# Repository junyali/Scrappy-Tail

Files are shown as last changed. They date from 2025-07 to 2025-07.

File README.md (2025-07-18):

# Scrappy Tail

A DIY USB 2.0 Hub with 4 Type-A ports and a Type-C input, with a cute 3D printed scrappy cat case!! :3

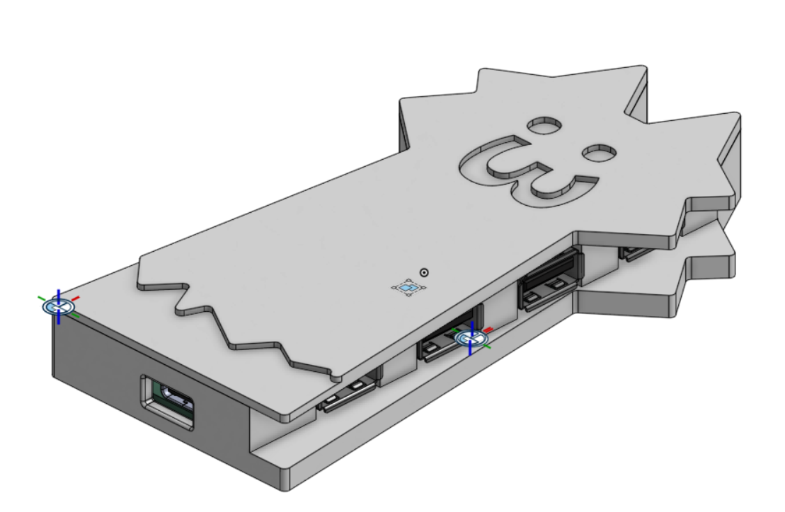
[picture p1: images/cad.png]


Scrappy Tail connects to your device using USB Type-C (hence the cable making it look like a tail!) and gives you 4 additional USB Type-A ports. It uses the SL2.1A hub controller, so it uses USB 2.0 interface and thus speeds are limited to 480Mbps

PCB designed in KiCAD and CAD designed in OnShape. 

# Preview

| Description | Image |
|---|---|
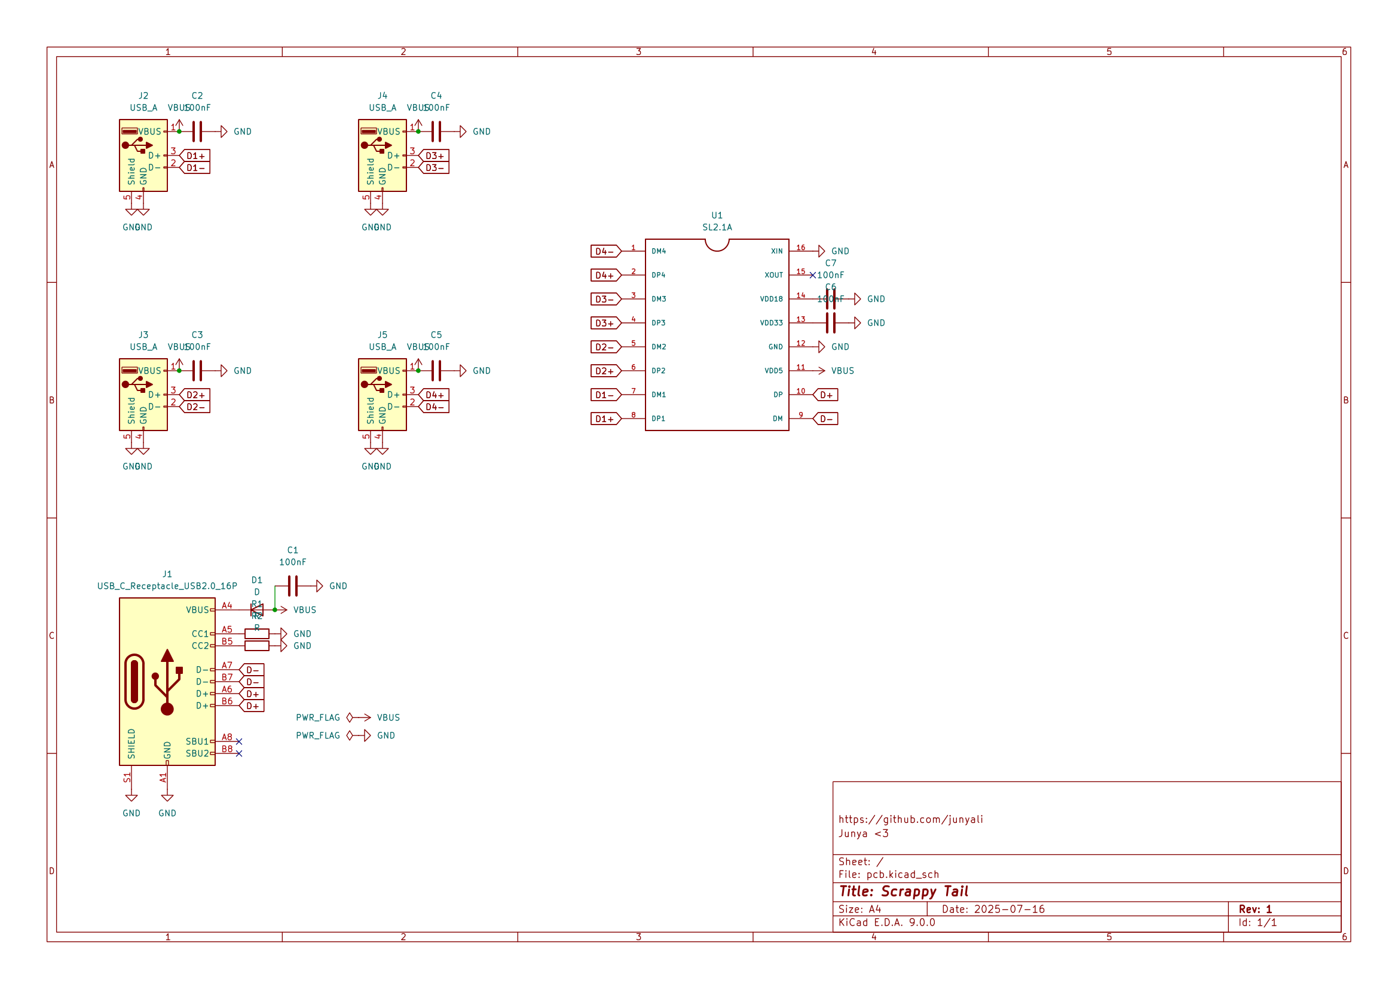
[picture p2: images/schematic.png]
| Schematic |  |
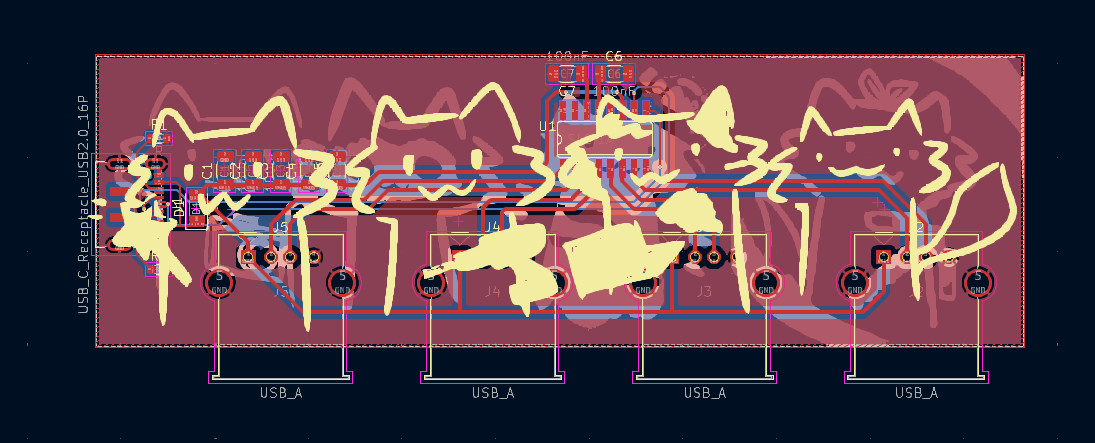
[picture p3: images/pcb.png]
| PCB |  |
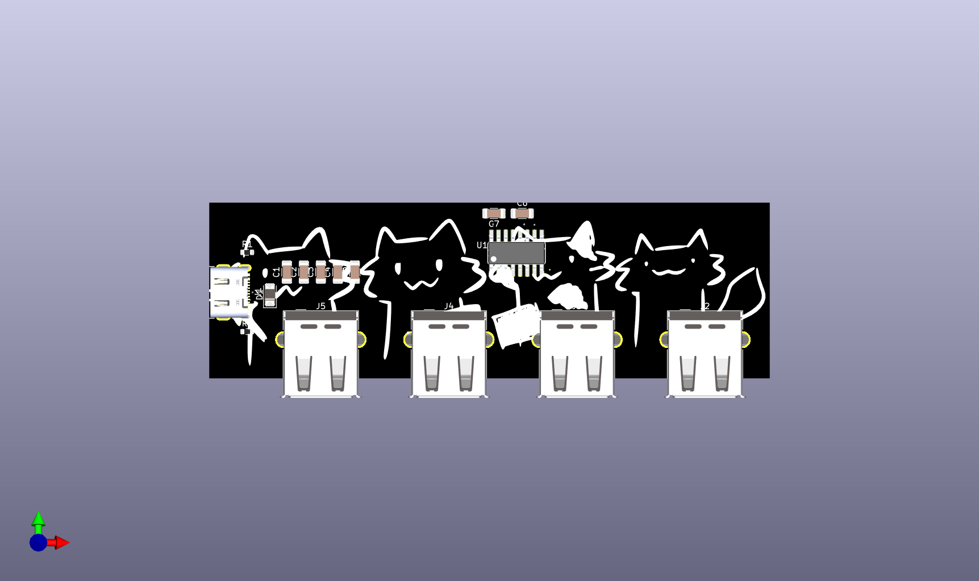
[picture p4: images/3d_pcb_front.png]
| 3D PCB Render Front |  |
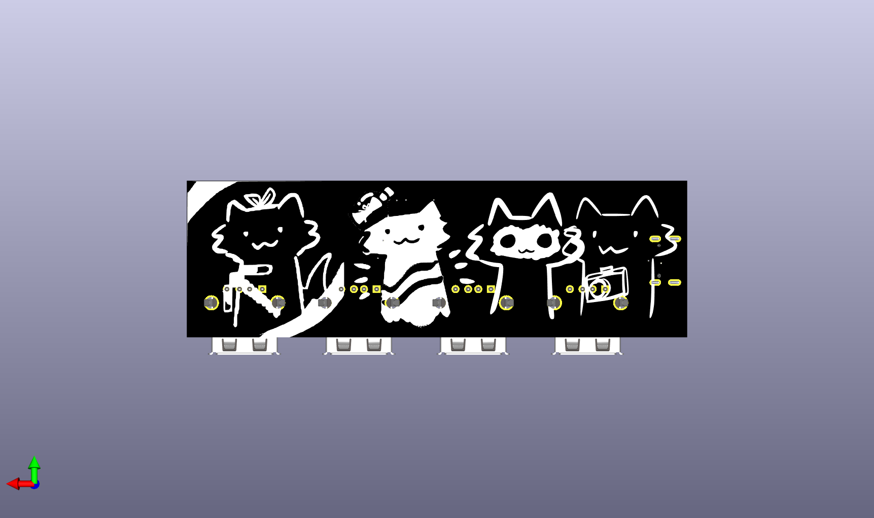
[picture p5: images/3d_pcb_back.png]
| 3D PCB Render Back  |  |
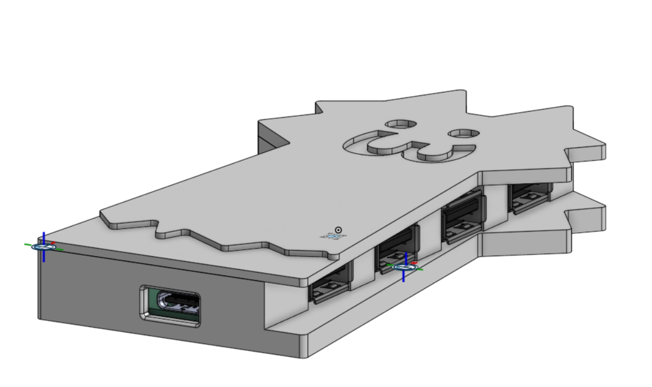
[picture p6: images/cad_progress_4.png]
| CAD + PCB |  |

# BOM

This one's a bit of an expensive one thanks to the PCBA fees.

See the original BOM under `bom.csv`

## PCB Prototype + individual components only

| Component | Quantity | LCSC Part # | Price (USD) | LCSC Link |
|---|---|---|---|---|
| 100uF Ceramic Capacitor | 7 | CL31A107MQHNNNE | 0.34 | https://lcsc.com/product-detail/Multilayer-Ceramic-Capacitors-MLCC-SMD-SMT_Samsung-Electro-Mechanics-CL31A107MQHNNNE_C15008.html |
| Schottky Diode 1206 | 1 | C466498 | 0.47 | https://lcsc.com/product-detail/Schottky-Diodes_High-Diode-SS14_C466498.html |
| USB C Receptacle JAE DX07S016JA1R1500 | 1 | C3197885 | 0.97 | https://lcsc.com/product-detail/USB-Connectors_JAE-DX07S016JA1R1500_C3197885.html |
| USB A Receptacle Molex 67643 Horizontal | 4 | C2765194 | 0.88 | https://lcsc.com/product-detail/USB-Connectors_MOLEX-67643-3911_C2765194.html |
| 5.1kΩ Resistor 0603 | 2 | C105580 | 0.12 | https://lcsc.com/product-detail/Chip-Resistor-Surface-Mount_YAGEO-RC0603FR-075K1L_C105580.html |
| CoreChips SL2.1A | 1 | C192893 | 1.31 | https://lcsc.com/product-detail/USB-HUB-Controllers_CoreChips-SL2-1A_C192893.html |
| PCB manufactured by JLCPCB (incl shipping, taxes, customs) | 5 | N/A | 3.10 | https://jlcpcb.com |
| Economic PCBA assembled by JLCPCB (incl shipping, taxes, customs) | 2 | N/A | 52.38 | https://jlcpcb.com |

Subtotal (excluding PCBA): `US$7.19`

Estimated cost (PCBA which includes parts and PCB): `US$55.48`

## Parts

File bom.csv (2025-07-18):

Designator | Footprint | Quantity | Value | LCSC Part # | Price | LCSC Link
C1, C2, C3, C4, C5, C6, C7 | 1206 | 7 | 100nF | CL31A107MQHNNNE | 0.34 | https://lcsc.com/product-detail/Multilayer-Ceramic-Capacitors-MLCC-SMD-SMT_Samsung-Electro-Mechanics-CL31A107MQHNNNE_C15008.html
D1 | 1206 | 1 | D | C466498 | 0.47 | https://lcsc.com/product-detail/Schottky-Diodes_High-Diode-SS14_C466498.html
J1 | USB_C_Receptacle_JAE_DX07S016JA1R1500_3D | 1 | USB_C_Receptacle_USB2.0_16P | C3197885 | 0.97 | https://lcsc.com/product-detail/USB-Connectors_JAE-DX07S016JA1R1500_C3197885.html
R1, R2 | 0603 | 2 | R | C105580 | 0.12 | https://lcsc.com/product-detail/Chip-Resistor-Surface-Mount_YAGEO-RC0603FR-075K1L_C105580.html
U1 | SO16 | 1 | SL2.1A | C192893 | 1.31 | https://lcsc.com/product-detail/USB-HUB-Controllers_CoreChips-SL2-1A_C192893.html

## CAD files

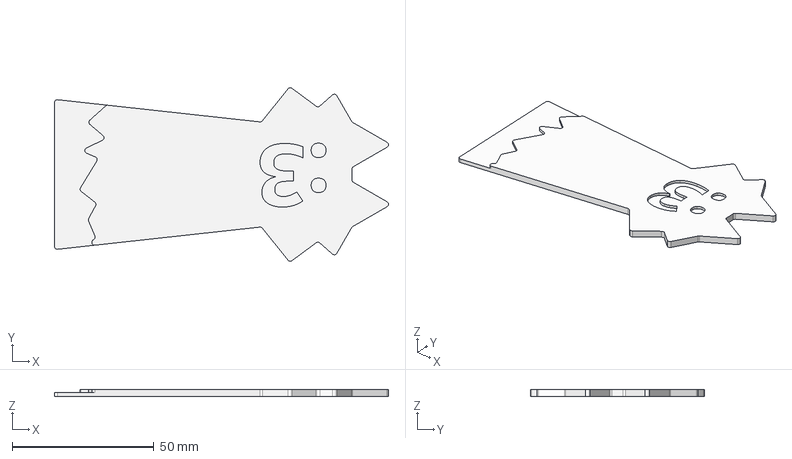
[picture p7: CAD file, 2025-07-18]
production/top.step
117.9 x 61.2 x 2.50 mm

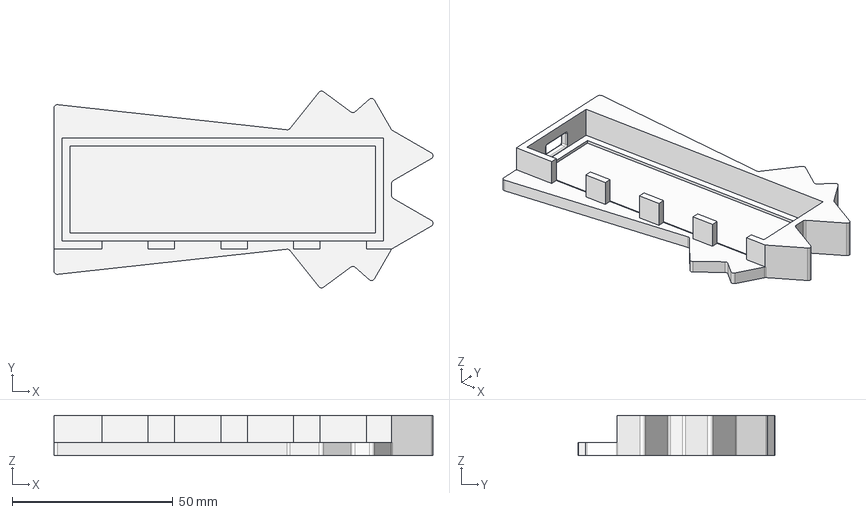
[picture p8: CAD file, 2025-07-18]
production/bottom.step
117.9 x 61.2 x 12.5 mm

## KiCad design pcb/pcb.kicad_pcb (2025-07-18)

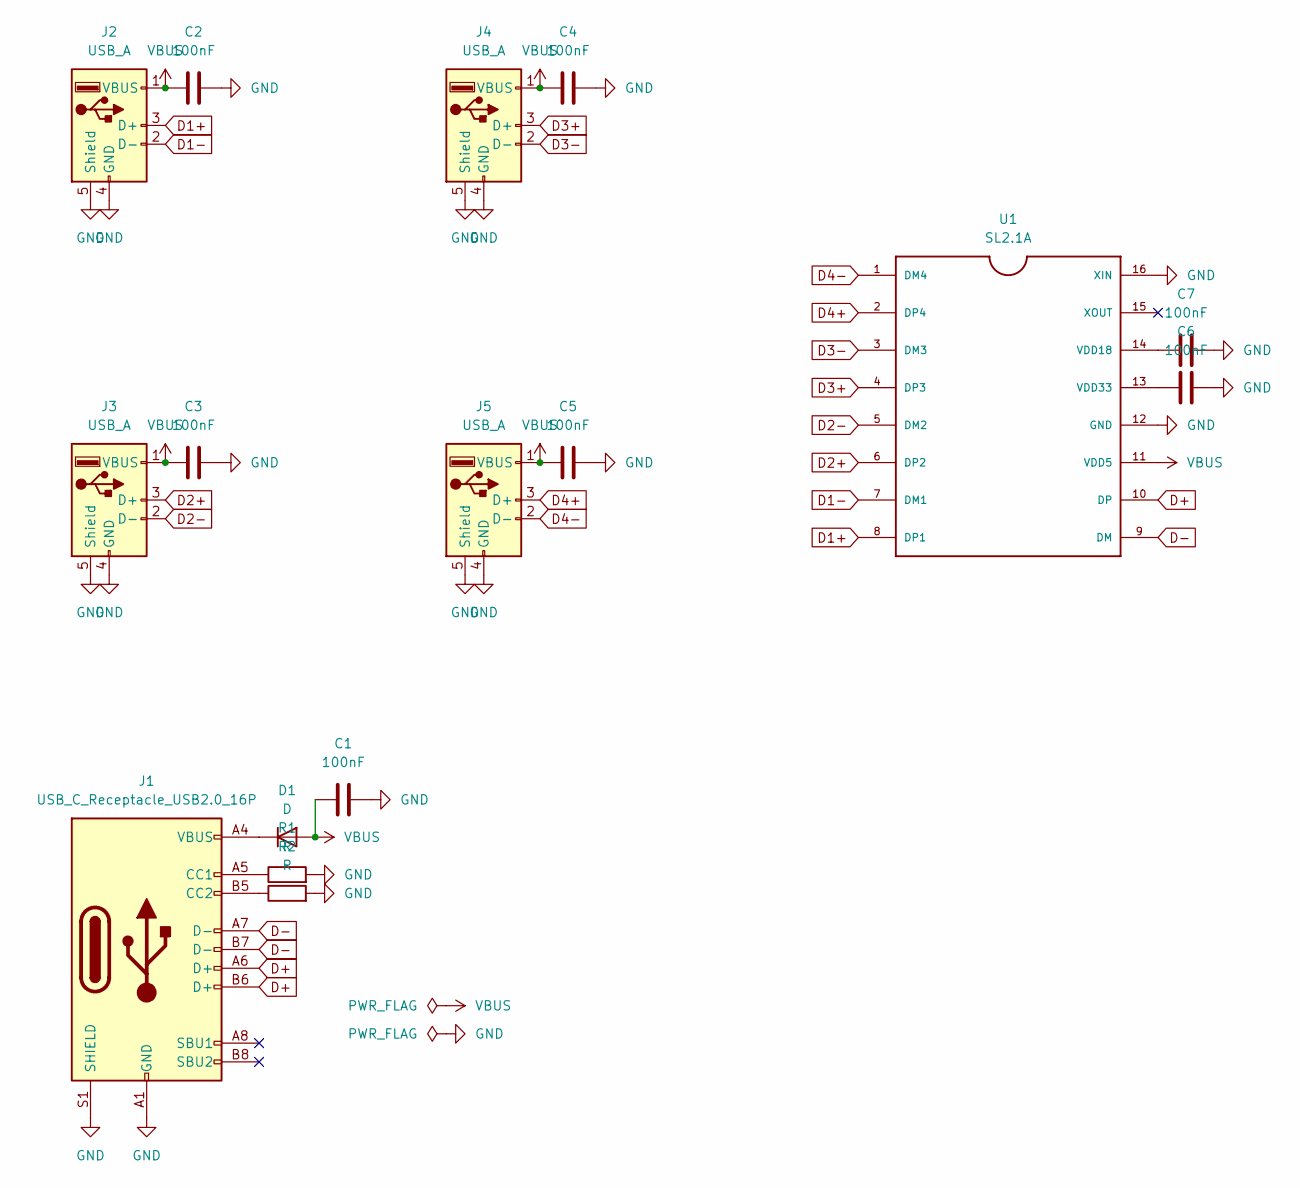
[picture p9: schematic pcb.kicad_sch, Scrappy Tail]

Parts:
C1, C2, C3, C4, C5, C6, C7: 100nF; C_1206_3216Metric; MPN CL31A107MQHNNNE
D1: D; D_1206_3216Metric; MPN C466498
J1: USB_C_Receptacle_USB2.0_16P; USB_C_Receptacle_JAE_DX07S016JA1R1500_3D; MPN C3197885
J2, J3, J4, J5: USB_A; USB_A_Molex_67643_Horizontal; MPN C2765194
R1, R2: R; R_0603_1608Metric; MPN C105580
U1: SL2.1A; SO16; MPN C192893

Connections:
D1+: J2.3 (D+), U1.8 (DP1)
D1-: J2.2 (D-), U1.7 (DM1)
D2+: J3.3 (D+), U1.6 (DP2)
D2-: J3.2 (D-), U1.5 (DM2)
D3+: J4.3 (D+), U1.4 (DP3)
D3-: J4.2 (D-), U1.3 (DM3)
D4+: J5.3 (D+), U1.2 (DP4)
D4-: J5.2 (D-), U1.1 (DM4)
D+: J1.A6 (D+), J1.B6 (D+), U1.10 (DP)
D-: J1.A7 (D-), J1.B7 (D-), U1.9 (DM)
GND: C1.2, C2.2, C3.2, C4.2, C5.2, C6.2, C7.2, J1.A1 (GND), J1.A12 (GND), J1.B1 (GND), J1.B12 (GND), J1.S1 (SHIELD), J2.4 (GND), J2.5 (Shield), J3.4 (GND), J3.5 (Shield), J4.4 (GND), J4.5 (Shield), J5.4 (GND), J5.5 (Shield), R1.2, R2.2, U1.12 (GND), U1.16 (XIN)
unnamed: D1.1 (K), J1.A4 (VBUS), J1.A9 (VBUS), J1.B4 (VBUS), J1.B9 (VBUS)
unnamed: J1.A5 (CC1), R1.1
unnamed: J1.B5 (CC2), R2.1
unnamed: C7.1, U1.14 (VDD18)
unnamed: C6.1, U1.13 (VDD33)
VBUS: C1.1, C2.1, C3.1, C4.1, C5.1, D1.2 (A), J2.1 (VBUS), J3.1 (VBUS), J4.1 (VBUS), J5.1 (VBUS), U1.11 (VDD5)

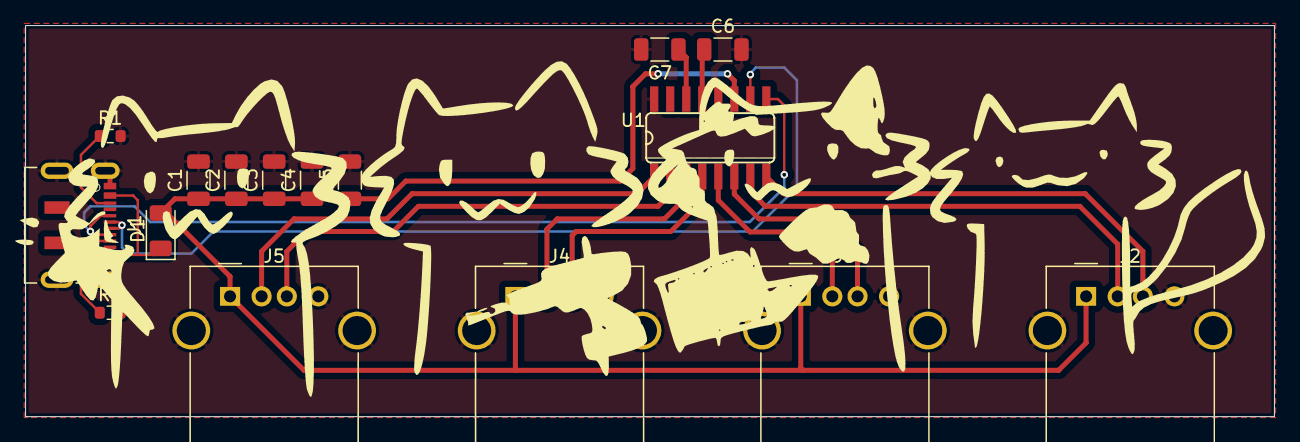
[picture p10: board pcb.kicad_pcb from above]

Board: 2 copper layers, 99.0 x 31.0 mm, 16 parts (0 on the bottom side), 17 nets.

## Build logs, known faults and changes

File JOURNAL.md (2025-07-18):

---
title: "Scrappy Tail"
author: "junyali"
description: "A USB Splitter Hub with a combination of Type-C and Type-A ports in the Scrappy Cat design :3"
created_at: "2025-07-04"
---

----

### Total Time Spent: ~15ish hours

# Scrappy Tail

## Entry 1 - 2025/07/04

### Time spent: 30 minutes of pre-research

USBs are... a complex thing. I decided I want to challenge myself into doing something special with them: a USB Hub. Before I took on this idea and turned it into something, research was definitely needed.

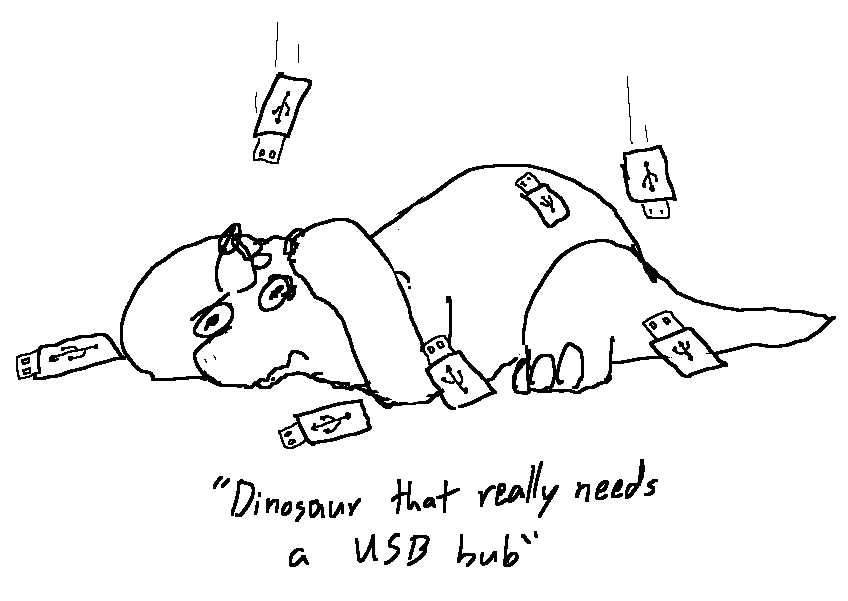
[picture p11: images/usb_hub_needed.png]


so in the world of growing technology, why go with USB-A when USB Type-C is the norm, the standard nowadays? of course i'm not going for anything crazy like USB 3.0 (or later) - that looks scary, or even thunderbolt :skull:. USB 2.0 was good enough for me, so here we go...

## Entry 2 - 2025/07/05

### Time spent: 5 hours

i've sort of had experience with USB Receptacles in KiCAD, but since I was learning how to use EasyEDA Pro Desktop, figured i might as well do it in EasyEDA. unfortunately that means i'll be using whatever symbol the manufacturer of the part is using, unlike the simple symbols in KiCAD, but i'll have to deal with it

ahh.... yeah, the USB Type-C experience... reversible but complex :sob:

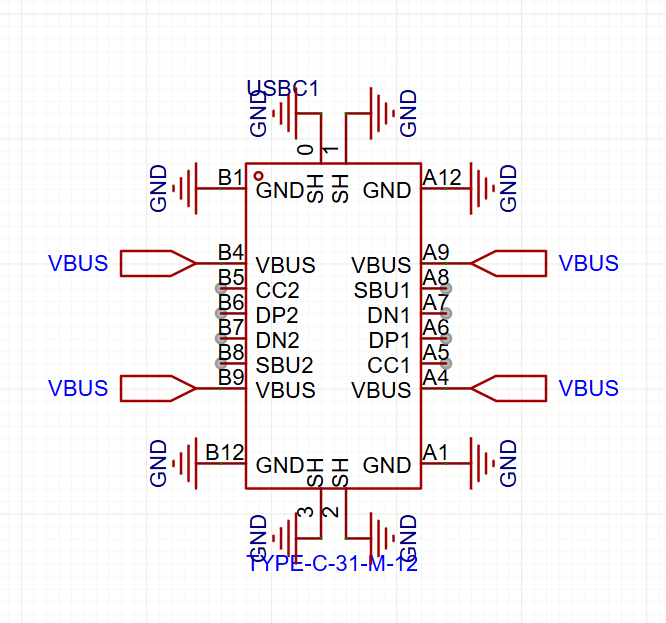
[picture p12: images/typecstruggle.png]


okay, that's much better! :p

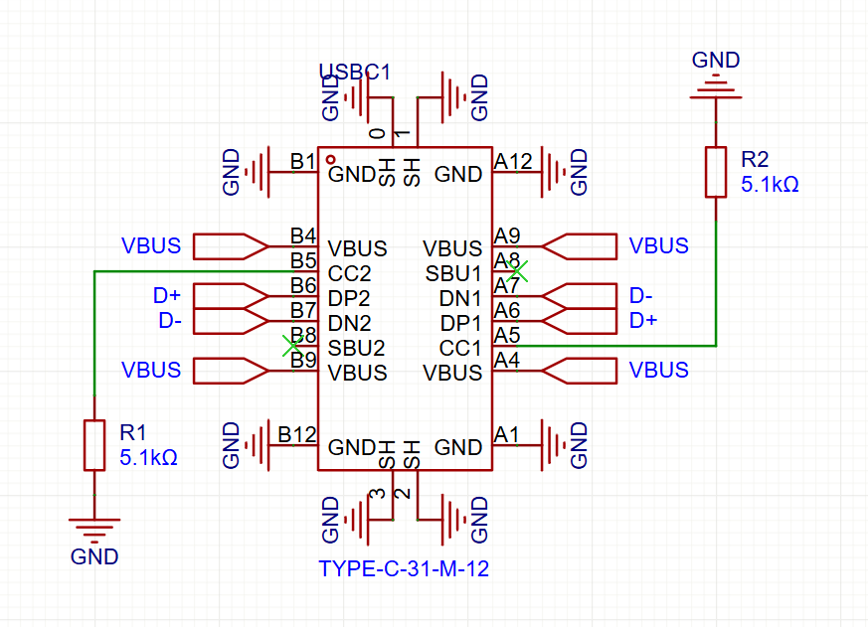
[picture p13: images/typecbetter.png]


yeah basically with type-c the other side is the reversible part, so it's pretty much the same.

i'm not doing anything fancy with protocols (thunderbolt, displayport, hdmi, etc) so SBU is unconnected, however i've added pull-down resistors to CC pins because they're not a pwr src!

*4 hours later...*

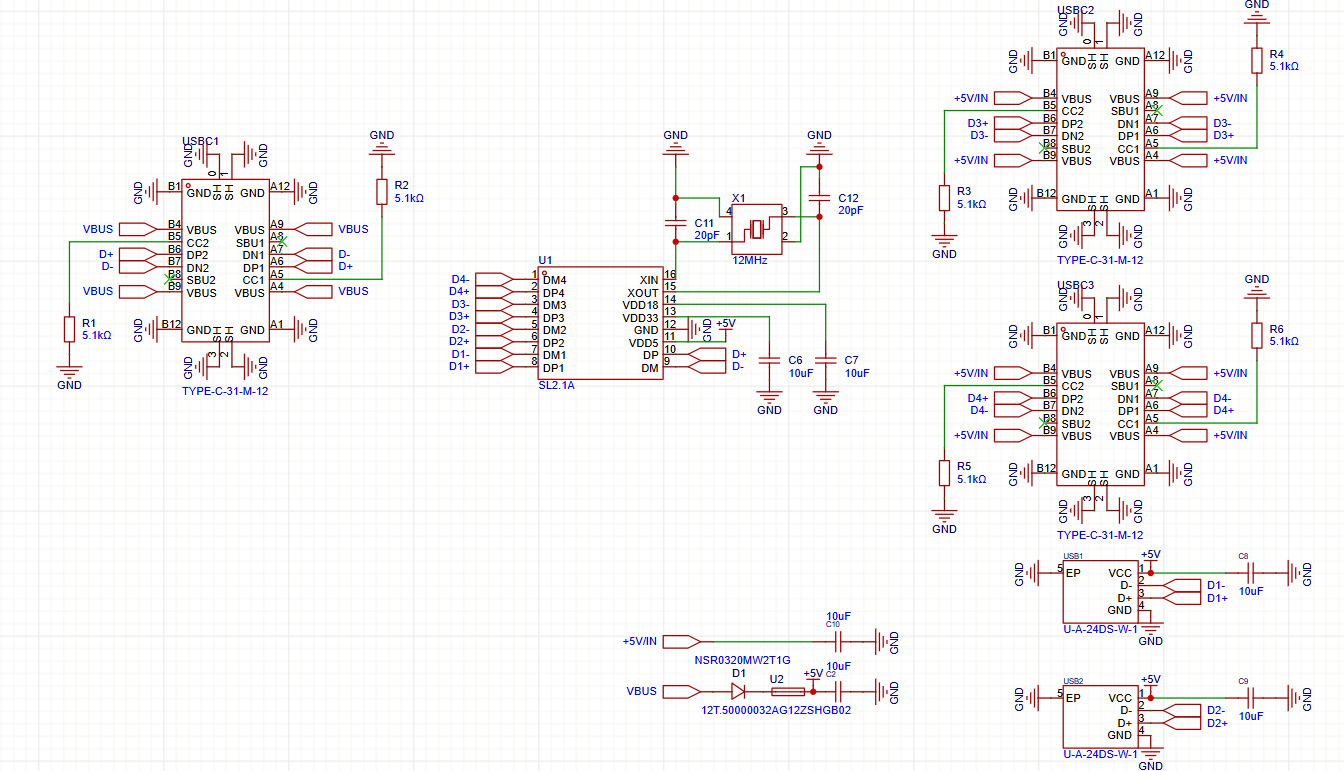
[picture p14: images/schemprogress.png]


yeah, it's messy but whatever, no DRC errors.

## Entry 3 - 2025/07/16

### Time spent: 3 hours

okay woah, it's been a while.

Undercity wrapped up, and it was a blast. as of right now i'm in germany, waiting for my transiting flight to Shanghai for yet another hackathon.

i decided to have a change of plan for this project, because i can't spend as much time, so i'm switching to KiCAD, and making some changes to some of the specifications.

SL2.1A controller remains the same, but i've decided to use 4 USB Type-A receptacles instead, however the schematic is pretty much the same.

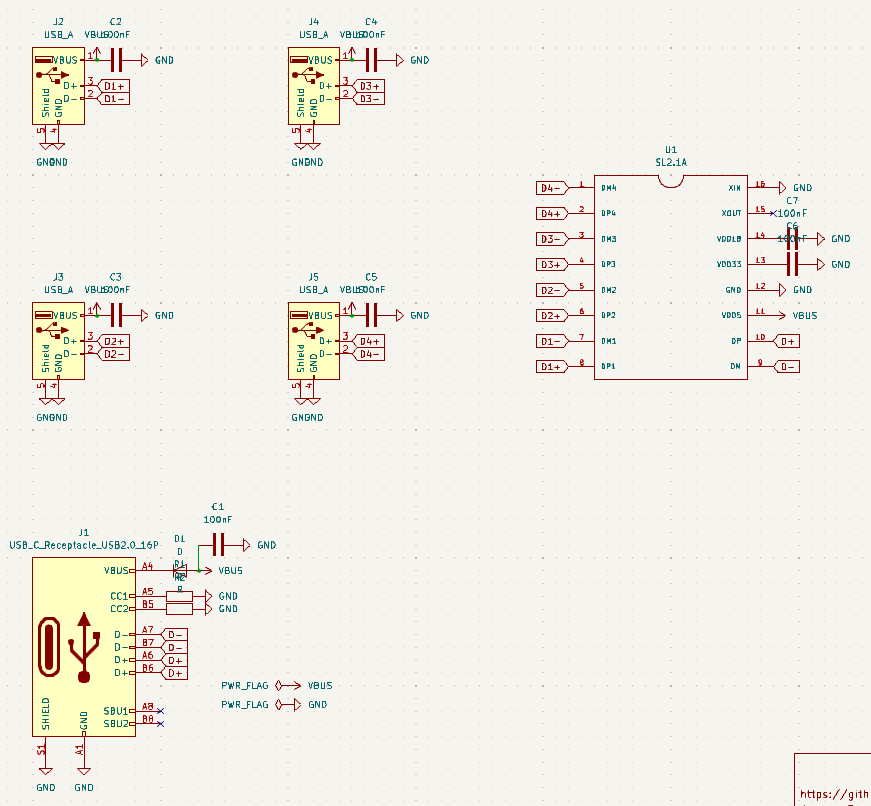
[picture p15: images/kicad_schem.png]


## Entry 4 - 2025/07/17

## Time spent: 2 hours

very tired, but i managed to get some wiring done, yay.....

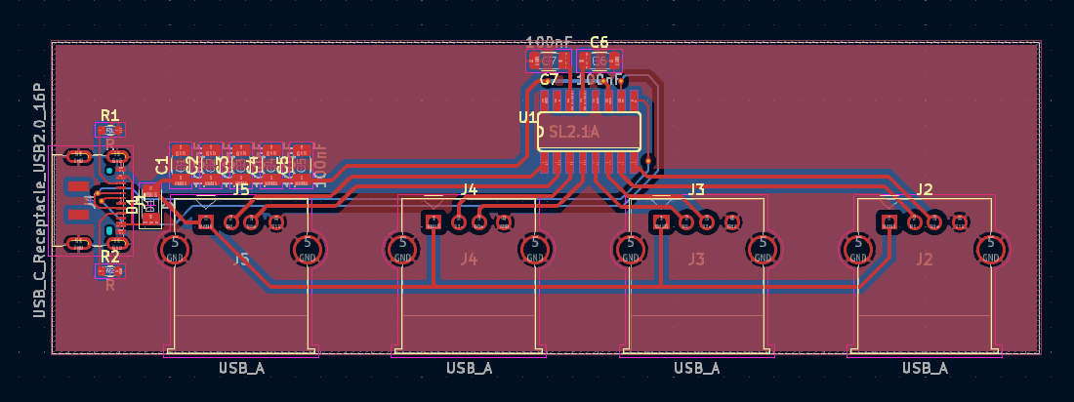
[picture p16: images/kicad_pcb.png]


i mean, i don't know how to make that look a better shape. usb type-c receptacle at the front (that's where the tail comes from) and usb type-a on the sides.

i've decided to space 8.0mm between each receptacle even though the USB specification recommends 12.0mm, because if i did that then my pcb would be longer than 100.0mm (expensive!)

let's add some silkscreen art, and what better way than to add all the scrappy cat pfps that Hack Clubbers have?!

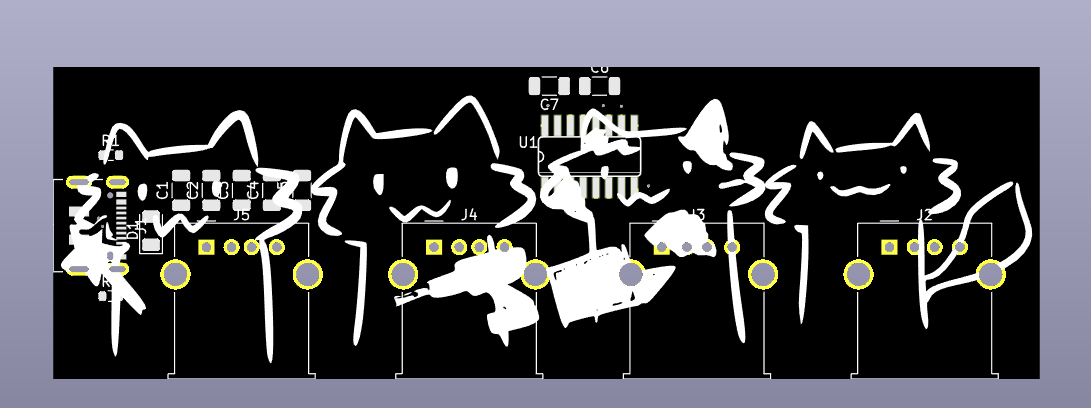
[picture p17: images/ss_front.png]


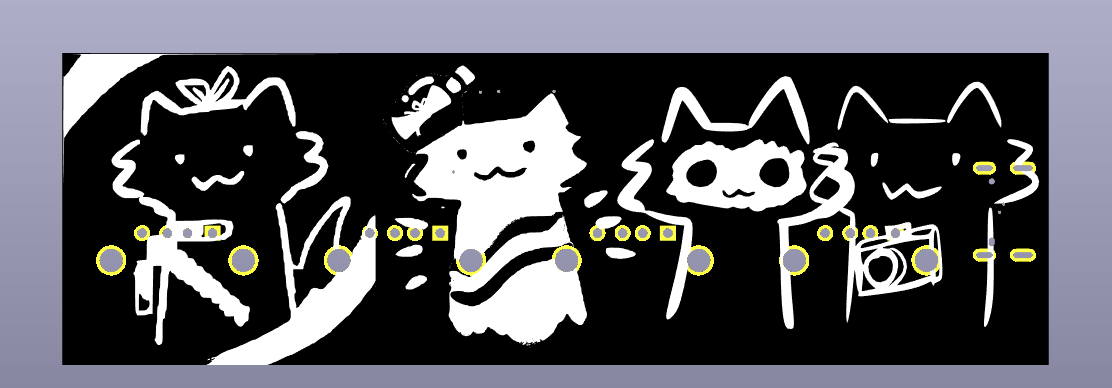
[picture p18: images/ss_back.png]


(3dmodels hidden)

shout out if you're on here btw :3 (i couldn't find anymore T-T)

yeah anyways, DRC no errors so all is good! (i just hope that JLCPCB is able to PCBA this as some of the footprints im using are wacky :sob:)

# Entry 5 - 2025/07/18

## Time spent: 4 hours

CAD time!

onshape as usual, and obviously, if i'm going for a scrappy cat design, then i'm totally gonna have scrappy cat case! i'm really bad at CAD though, so i though i made the rectangular part first, then gradually built the cat shape on top, it would come out fine.

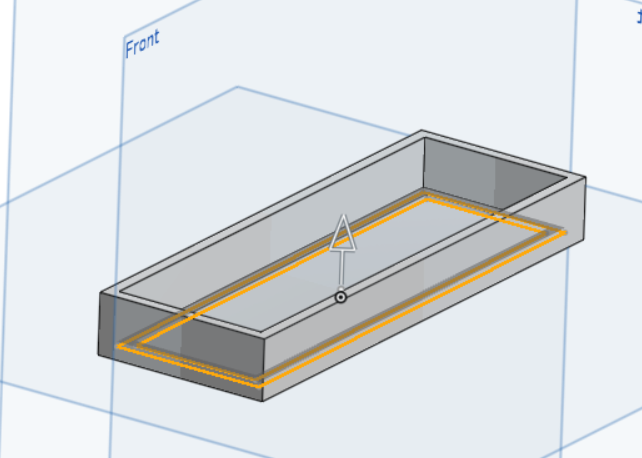
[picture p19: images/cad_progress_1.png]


it's a.. box. yay?

okey, so i drew some lines here and there, and made some cutouts for my usb receptacles, and now it's starting to take shape!

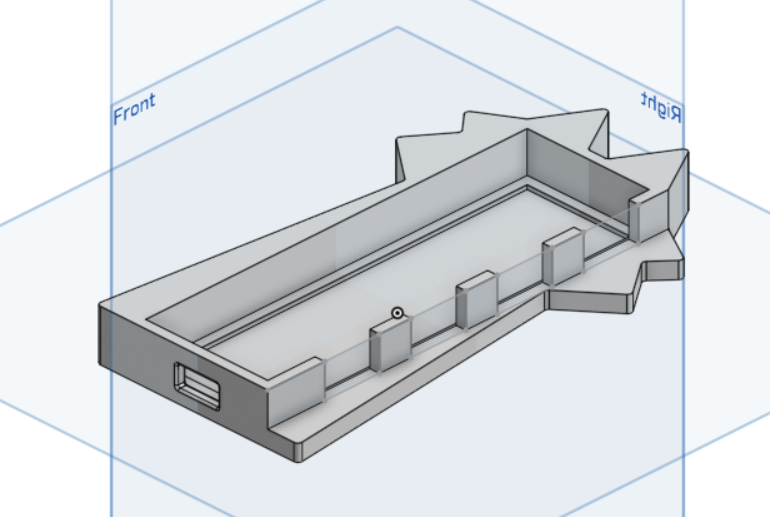
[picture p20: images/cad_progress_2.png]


and now create the lid...

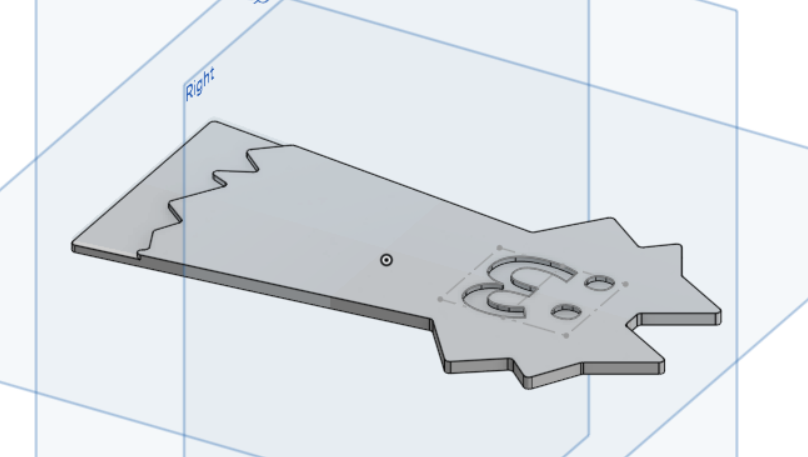
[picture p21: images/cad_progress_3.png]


combine together for the final case!



anyways uhh. i think that's BASICALLY it!

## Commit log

2025-07-18 Add PCB
    [pcb.kicad_pcb, pcb.kicad_sch]
2025-07-18 Update PCB
    [pcb.kicad_pcb]
2025-07-18 Add CAD files
    [bottom.step, top.step]
2025-07-18 Add production files
    [bottom.step, top.step]
2025-07-18 Add bom.csv (thank .gitignore)
    [bom.csv]
2025-07-18 Add bom.csv (thanks .gitignore)
    [bom.csv]
2025-07-18 Add PaP files
    [designators.csv, positions.csv]
